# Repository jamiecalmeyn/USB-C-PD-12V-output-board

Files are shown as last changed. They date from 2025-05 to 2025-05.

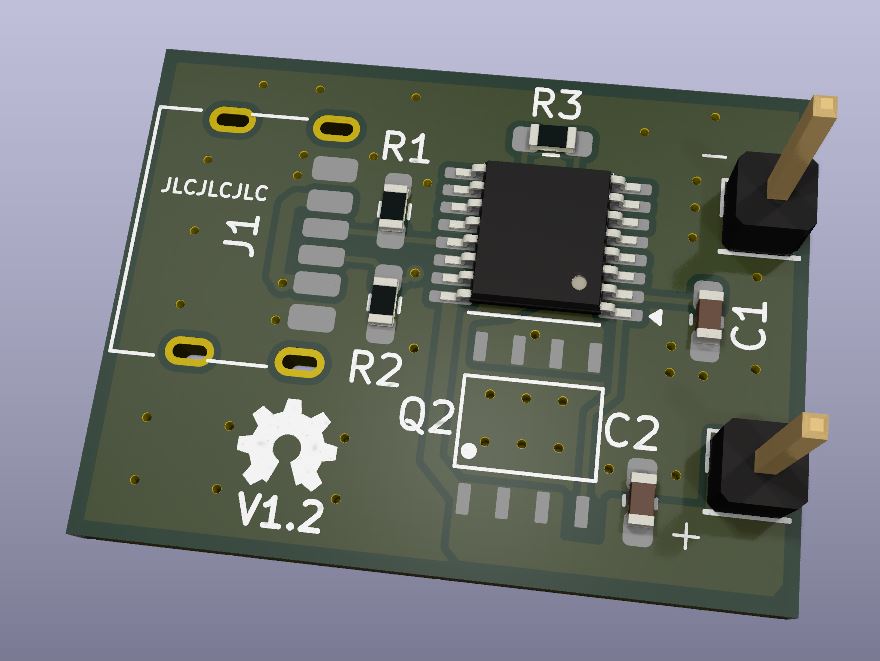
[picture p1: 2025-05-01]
USB-PD_BarrelJack/Rendered Image.JPG

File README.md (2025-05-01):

# USB-C PD 12V output board
Powered by the IP2721_MAX12
## PCB
Rendered Image

Upgrade your legacy gear with modern USB-C power. This compact board delivers a 12V output using the IP2721_MAX12 USB-C Power Delivery controller.

Whether you're retrofitting old tech or building something new, this board offers a simple, reliable way to tap into USB-C PD at 12V. It uses the HRO_TYPE-C-31-M-17 USB connector.
It should be able to handle 1.5A of current based on PCB track width.



*Board tested with 1.5A of current*



*Ripple under a 1.5A load, ripple can vary based on the USB-C charger. Test conducted with the **65W USB-C GaN iFixit Fast Charger***
## IP2721_MAX12

⚠️ Important: Use the Correct Chip

Be sure to use the **IP2721_MAX12** chip.

Using the standard **IP2721** (without the _MAX12 suffix) will result in 20V output, which could damage 12V devices. Double-check your part number!
Do note that the 12V is an optional voltage output in the USB-C PD standard, not every charger has a 12V output mode. 
## Schematic
 Schematic

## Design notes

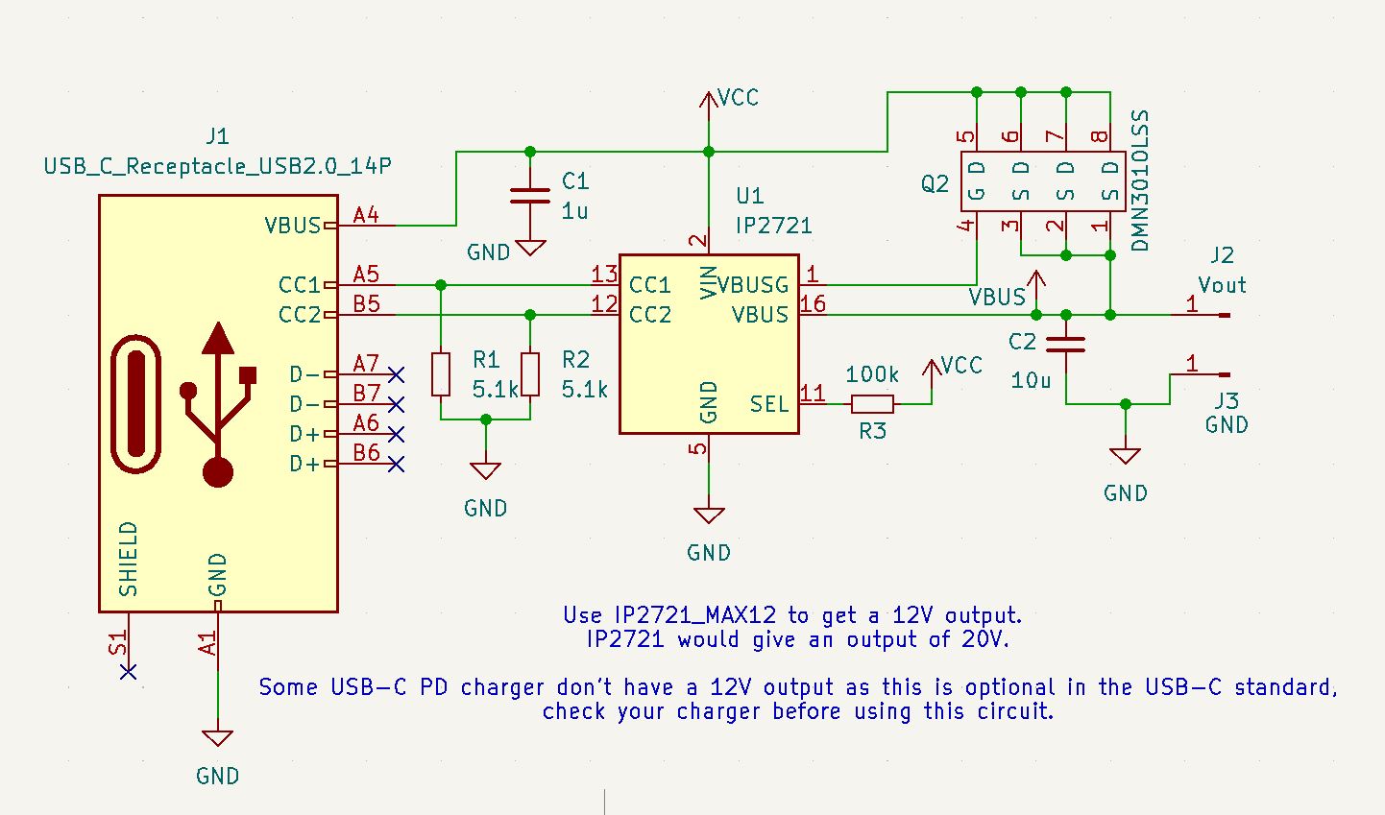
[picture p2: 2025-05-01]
USB-PD_BarrelJack/Schematic.JPG

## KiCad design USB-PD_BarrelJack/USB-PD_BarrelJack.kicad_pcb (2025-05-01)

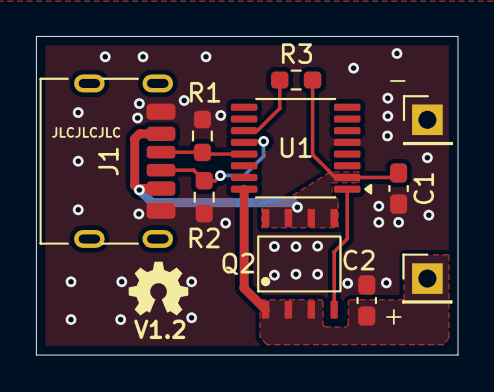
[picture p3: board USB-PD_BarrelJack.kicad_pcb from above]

Board: 2 copper layers, 23.4 x 17.7 mm, 10 parts (0 on the bottom side), 7 nets.

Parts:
C1: 1u; C_0603_1608Metric_Pad1.08x0.95mm_HandSolder
C2: 10u; C_0603_1608Metric_Pad1.08x0.95mm_HandSolder
J1: USB_C_Receptacle_USB2.0_14P; USB_C_Receptacle_HRO_TYPE-C-31-M-17
J2: Vout; PinHeader_1x01_P2.54mm_Vertical
J3: GND; PinHeader_1x01_P2.54mm_Vertical
Q2: DMN3010LSS
R1, R2: 5.1k; R_0603_1608Metric_Pad0.98x0.95mm_HandSolder
R3: 100k; R_0603_1608Metric_Pad0.98x0.95mm_HandSolder
U1: IP2721; TSSOP-16_4.4x5mm_P0.65mm

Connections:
GND: C1.2, C2.2, J1.A12 (GND), J1.B12 (GND), J3.1, R1.2, R2.2, U1.5 (GND)
unnamed: J1.A5 (CC1), R1.1, U1.13 (CC1)
unnamed: J1.B5 (CC2), R2.1, U1.12 (CC2)
unnamed: Q2.4 (G), U1.1 (VBUSG)
unnamed: R3.1, U1.11 (SEL)
VBUS: C2.1, J2.1, Q2.1 (S), Q2.2 (S), Q2.3 (S), U1.16 (VBUS)
VCC: C1.1, J1.A9 (VBUS), J1.B9 (VBUS), Q2.5 (D), Q2.6 (D), Q2.7 (D), Q2.8 (D), R3.2, U1.2 (VIN)
